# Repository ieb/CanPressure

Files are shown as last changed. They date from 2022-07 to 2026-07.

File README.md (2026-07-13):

# Can Pressure sender

* Emits PGN  130310L  Outside Environmental parameters and 130311L Environmental parameters with temperature, pressure, humidity from a BME280 sensor.
* Draws about 10-15mA. Uses a Attiny3224, MCP2551 CAN using an 8MHz crystal, and TJ1050.
* Attiny runs at 16MHz, but could almost certainly run slower for lower power consumption.
* PCB in pcb/ measures 66mmx27mm and is powered by 12v from NMEA2000 bus, 5V via a AMS1117, BMP280 module has its own 622K 3v regulator and level shifters.
* Needs a UDPI Programmer (I am using a UNO based programmer)
* Header for TTL Serial debugging using single character command line input.

Note, if the MCP Crystal does not match the code, when the device is plugged in it will address claim at the wrong bus frequency causing all other devices on the bus to start to fail. Check before programming that the device is running with an 8MHz MCP crystal. Change the code if using a 16MHz crystal.

# Pins and Layout

    -------------------------------------------
    |             a b c d e                   |
    | A                             AMS1117   |
    | B  TJ1050                               |
    | C                   ATTiny              |
    | D        MCP2551    3224       BME280   |
    |                                         |
    -------------------------------------------

    Debug and Programming Header
    a GND
    b 5V
    c UDPI
    d RX
    e TX

    NMEA2000 Interface
    A 12V
    B GND
    C CanL
    D CanH





# Command line on TTL

    Battery Monitor - key presses
        - 'h' or '?' to show this message
        - 's' show status
        - 'd' toggle diagnostics
        - 'r' read sensor
        - 'S' setup
        - 'R' reset
        - 'F' factory reset

* R will cause the Attiny to reboot.
* S enters setup allowing some EEPROM parameters to be set 
* F resets the EEPROM to the Factory settings
* r reads the sensors and dumps to serial.
* d toggles disagnostic output which includes CAN Frame data 
* s reports current status including packet counts, MCP Voltage and temperature.

# Developing

* Uses PlatformIO in VSCode
* Before flashing for the first time set the fuses to ensure that the chip has the correct clock. `pio run -t fuses`
* To build `pio run -t upload`

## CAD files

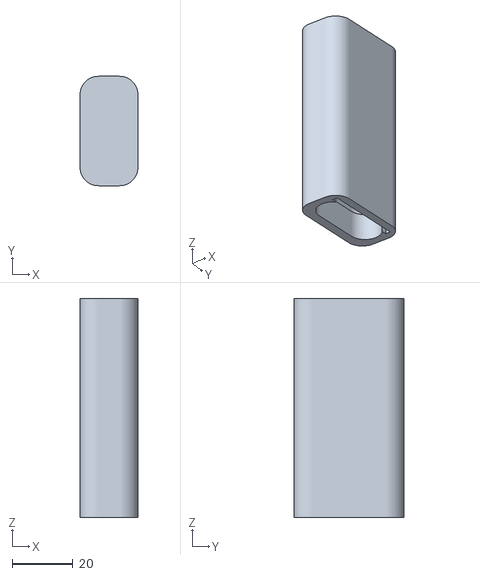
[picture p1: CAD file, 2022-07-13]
case/case.stl
19.0 x 36.0 x 72.0

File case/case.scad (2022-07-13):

$fn=100;
module tube(d=15,w=30,h=70) {
    translate([0,(w-d)/2,0])
    cylinder(d=d,h=h);
    translate([0,-(w-d)/2,0])
    cylinder(d=d,h=h);
    translate([-d/2,-(w-d)/2,0])
    cube([d,(w-d),h]);
}
module tube2(d=10,w=33,h=70,t=16) {
   
    translate([(t-d)/2,(w-d)/2,0])
    cylinder(d=d,h=h);
    translate([-(t-d)/2,(w-d)/2,0])
    cylinder(d=d,h=h);
    translate([-(t-d)/2,-(w-d)/2,0])
    cylinder(d=d,h=h);
    translate([(t-d)/2,-(w-d)/2,0])
    cylinder(d=d,h=h);
    
    translate([-(t-d)/2,-(w)/2,0])
    cube([(t-d),w,h]);
    translate([-(t)/2,-(w-d)/2,0])
    cube([t,(w-d),h]);
    
}
module board() {
    translate([4.5,-15,0])
    cube([2,30,67]);
    translate([0,-(30-12)/2,0])
    cylinder(d=12,h=12);
    translate([0,(30-12)/2,0])
    cylinder(d=12,h=12);
    translate([-(12)/2,-(30-12)/2,0])
    cube([12,(30-12),12]);
    
}

difference() {
    translate([0,0,0])
tube2(d=12,w=36,h=72,t=19);
    translate([0,0,10])
tube2(h=(70-12));
translate([0,0,-1])
board();
}

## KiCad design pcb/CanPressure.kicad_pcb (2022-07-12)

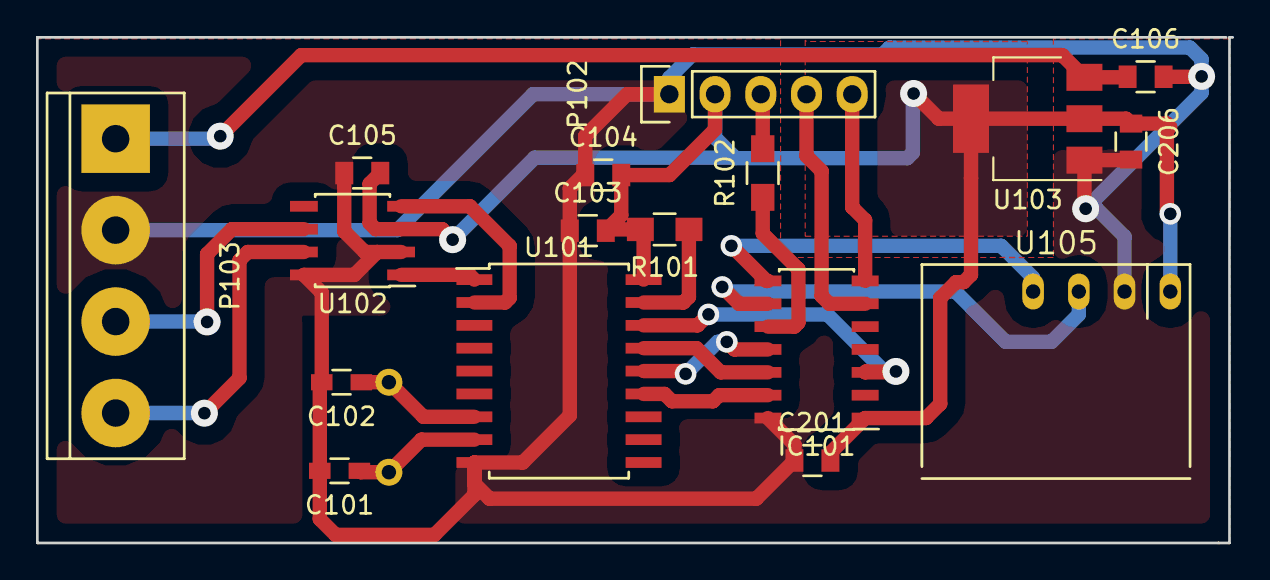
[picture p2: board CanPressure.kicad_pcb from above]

Board: 2 copper layers, 66.4 x 28.1 mm, 18 parts (1 on the bottom side), 20 nets.

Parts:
C101, C102: 22pF; R_0603_HandSoldering
C103, C106, C206: 10uF; C_0805
C104, C105, C201: 100nF; C_0805
IC101: ATTINY3224-SS; SOIC-14_3.9x8.7mm_Pitch1.27mm
P102: CONN_5; Pin_Header_Straight_1x05
P103: CAN; bornier4
R101: 10K; R_0805_HandSoldering
R102: 270R; R_0805_HandSoldering
U101: MCP2515; SOIC-18W_7.5x11.6mm_Pitch1.27mm
U102: TJA1050; SOIC-8_3.9x4.9mm_Pitch1.27mm
U103: NCP1117ST50T3G; SOT-223-3Lead_TabPin2
U105: BMP280
X101: 8MHz; Resonator-2pin_w10.0mm_h5.0mm

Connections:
5V: C103.2, C104.2, C105.2, C201.2, C206.1, IC101.1, P102.2, R101.2, U101.18, U102.3, U103.2, U105.1
12v: C106.1, P103.1, U103.3
CANCS: IC101.3, U101.16
CANH: P103.4, U102.7
CANL: P103.3, U102.6
GND: C101.2, C102.2, C103.1, C104.1, C105.1, C106.2, C201.1, C206.2, IC101.14, P102.1, P103.2, U101.9, U102.2, U102.8, U103.1, U105.2
MISO: IC101.12, U101.15
MOSI: IC101.11, U101.14
unnamed: C101.1, U101.8, X101.1
unnamed: C102.1, U101.7, X101.2
unnamed: P102.3, R102.2
unnamed: R101.1, U101.17
unnamed: U101.1, U102.1
unnamed: U101.2, U102.4
RX: IC101.6, P102.4
SCK: IC101.13, U101.13
SCL: IC101.9, U105.3
SDA: IC101.8, U105.4
TX: IC101.7, P102.5
UDPI: IC101.10, R102.1

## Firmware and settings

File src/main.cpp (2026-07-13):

#include <Arduino.h>
#include <Wire.h>
#include <SPI.h>
#include "BME280_t.h"                                                   // import BME280 template library
#include "SmallNMEA2000.h"
#include "commandline.h"
#include "version.h"



const SNMEA2000ProductInfo productInfomation PROGMEM={
                                       1300,                        // N2kVersion
                                       44,                         // Manufacturer's product code
                                       "Baro",    // Manufacturer's Model ID
                                       "1.2.3.4 (2017-06-11)",     // Manufacturer's Software version code
                                       "5.6.7.8 (2017-06-11)",      // Manufacturer's Model version
                                       "0000002",                  // Manufacturer's Model serial code
                                       0,                           // SertificationLevel
                                       1                            // LoadEquivalency
};
const SNMEA2000ConfigInfo configInfo PROGMEM={
      "Pressure Monitor",
      "Luna Technical Area",
      "https://github.com/ieb/CanPressure"
};

uint8_t pgnEnableRegister = 0xff;


const unsigned long txPGN[] = { 
    130310L, //  Outside Environmental parameters
    130311L,  // Environmental parameters
    130313L,  // Humidity parameters
    130314L,  // Pressure parameters
    130316L,  // Temperature parameters
    SNMEA200_DEFAULT_TX_PGN
};
const unsigned long rxPGN[] = { 
  SNMEA200_DEFAULT_RX_PGN
};

const SNMEA2000DeviceInfo devInfo = SNMEA2000DeviceInfo(
  99923232,   // device serial number
  130,  //Atmospheric Function
  85 // Enternal Environment monitor
);

#define DEVICE_ADDRESS 25
#define SNMEA_SPI_CS_PIN PIN_PA5  


PressureMonitor pressureMonitor = PressureMonitor(DEVICE_ADDRESS, 
          &devInfo, 
          &productInfomation, 
          &configInfo, 
          &txPGN[0], 
          SNMEA200_DEFAULT_TX_PGN_LEN+5,
          &rxPGN[0],
          SNMEA200_DEFAULT_RX_PGN_LEN,
          SNMEA_SPI_CS_PIN
);
CommandLine commandLine = CommandLine(&Serial, &pressureMonitor);
BME280<> BMESensor;                                                     // instantiate sensor


bool diagnostics = false;
void setDiagnostics(bool enabled) {
  pressureMonitor.setDiagnostics(enabled);
  diagnostics = enabled;

}

#define READING_UPDATE_PERIOD 2000

void sendReading() {
  static unsigned long lastReading=0;
  static unsigned long last130310=0;
  static unsigned long last130311=0;
  static unsigned long last130313=0;
  static unsigned long last130314=0;
  static unsigned long last130316=0;
  static byte sid = 0;
  unsigned long now = millis();
  if ( now-lastReading > READING_UPDATE_PERIOD ) {
    lastReading = now;
    BMESensor.refresh();
    if ( diagnostics ) {
      Serial.print(F("Reading pressure:"));
      Serial.print(BMESensor.pressure);
      Serial.print(F(" temperature:"));
      Serial.print(BMESensor.temperature);
      Serial.print(F(" humidity:"));
      Serial.println(BMESensor.humidity);
    }
    sid++;
  }
#define MAIN_CABIN_TEMPERATURE 4
#define INSIDE_HUMIDITY 0
#define ATMOSPHERIC 0
  if ( commandLine.periodPGN130310 != 0 && now-last130310 > commandLine.periodPGN130310) {
    last130310 = now;
    pressureMonitor.sendOutsideEnvironmentParameters(sid, SNMEA2000::n2kDoubleNA,  CToKelvin(BMESensor.temperature), BMESensor.pressure);    
  }
  if ( commandLine.periodPGN130311 != 0 && now-last130311 > commandLine.periodPGN130311) {
    last130311 = now;
    pressureMonitor.sendEnvironmentParameters(sid, BMESensor.pressure, MAIN_CABIN_TEMPERATURE, CToKelvin(BMESensor.temperature), INSIDE_HUMIDITY, BMESensor.humidity);
  }
  if ( commandLine.periodPGN130313 != 0 && now-last130313 >   commandLine.periodPGN130313) {
    last130313 = now;
      // NMEA2000 v3 messages, more resolution.
      pressureMonitor.sendHumidity(sid, INSIDE_HUMIDITY, 0, BMESensor.humidity);
  }
  if ( commandLine.periodPGN130314 != 0 && now-last130314 >  commandLine.periodPGN130314) {
    last130314 = now;
    pressureMonitor.sendPressure(sid, ATMOSPHERIC, 0, BMESensor.pressure);
  }
  if ( commandLine.periodPGN130316 != 0 && now-last130316  > commandLine.periodPGN130316) {
    last130316 = now;
    pressureMonitor.sendTemperature(sid, MAIN_CABIN_TEMPERATURE, 0, CToKelvin(BMESensor.temperature));
  }
}


void setup() {
  Serial.begin(115200);
  Serial.println(F("Pressure monitor start"));
  Serial.print(F("Version: "));
  Serial.println(F(GIT_SHA1_VERSION));
  if (GIT_LOCAL_CHANGES > 0) {
    Serial.print(F("With Local Changes: "));
    Serial.println(GIT_LOCAL_CHANGES);
  }   
  commandLine.begin();


  Wire.begin();
  while (!BMESensor.begin()) {
    Serial.println(F("Failed to start Sensor, retry in 5s"));
    delay(5000);
  }
  Serial.println(F("Sensor Ok"));
  pressureMonitor.setSerialNumber(commandLine.serialNumber);
  pressureMonitor.setDeviceAddress(commandLine.deviceAddress);
  Serial.println(F("Opening CAN with 8MHz MCP Crystal"));
  while ( !pressureMonitor.open() ) {
    Serial.println(F("Failed to start NMEA2000, retry in 5s"));
    delay(5000);
  }
  Serial.println(F("Opened, MCP2515 Operational"));
  Serial.println(F("Running..."));
}

void loop() {
  sendReading();
  pressureMonitor.processMessages();
  commandLine.checkCommand();
}

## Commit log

2022-07-12 Working in test harness with a MCP2515 module
    [CanPressure.kicad_pcb, CanPressure.sch]
2022-07-12 Fixed bug with precision on doubles and fixed sending NMEA2000v3 messages
    [main.cpp]
2022-07-13 Fixed some bugs in the setup code
    [main.cpp]
2022-07-13 Added 3d printed case
    [case.scad, case.stl]
2026-07-13 Notes on MCP Crystal and corrected serial number
    [main.cpp]
